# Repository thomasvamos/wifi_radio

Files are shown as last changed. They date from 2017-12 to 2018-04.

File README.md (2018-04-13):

# Raspberry-PI Wifi-Radio
My attempt to build a retro wifi radio from scratch using a raspberry pi, arduinos encased in an old radio Loewe Opta Bella-Luxus 2711W. I started the project in 2014 and worked on it sporadically, when I had time and motivation.

# Getting started
## Prerequisites
You will need the following hardware if you want to rebuilt this radio as it is:
* 1 x raspberry pi (I used a Raspberry Pi Model B Rev 2.0)
* 2 x Arduino Pro Mini
* 1 x hd44780 4x20 LCD Display
* 2 x push-button rotary encoders
* 1 x 5V/3.3V Logic Level Converter
* 1 x PAM8403 3W Amplifier
* 2 x 3 Ohm Speakers
* 1 x wifi dongle
* 1 x 25 Watt power source
* 1 x USB Soundcard (optional)
* Cables and passive components

The hardware used in the current setup is not optimal, as the project started with some components I had laying around and grew over time. Feel free to change it to your taste.

The following schematic shows, how the hardware is tied together:
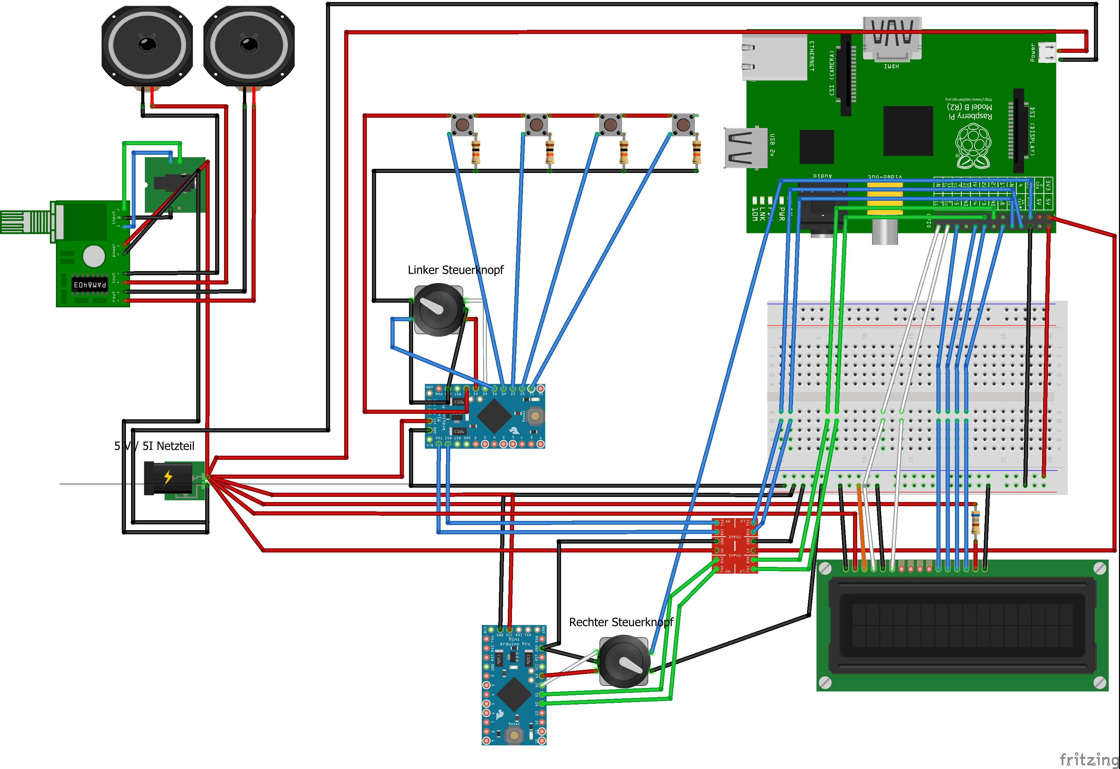
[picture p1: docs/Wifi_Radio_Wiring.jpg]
Radio schematic


## Installation
The project is quite hardware dependent, so you will have to do some configuration up front. [This](https://www.raspberrypi.org/documentation/configuration/wireless/wireless-cli.md) guide will help you, if you don't know how to connect your RPI to a wifi and [this](https://www.raspberrypi.org/documentation/remote-access/ssh/guide) one to set up SSH access. As the GPIO pins of the raspberry pi are limited, one of the arduinos is communicating to the RPI over serial communication. By default, the RPIs serial port is configured for console input/output. [This](http://www.instructables.com/id/Read-and-write-from-serial-port-with-Raspberry-Pi/) guide shows you how to disable it for Raspbian and [this](http://www.hobbytronics.co.uk/raspberry-pi-serial-port) one if you intend to run the radio on debian.

One of my goals for the radio was to completely cut off the power supply if the RPI shuts down. I did not find any suitable solutions so I designed a circuit for this purpose. You can find the schematics in the /docs folder. The RPI can be configured to set a pin from high to low if it shuts down. The curcuit probes this pin and cuts of power, if it is set to low. The following line has to be added to `/boot/config.txt` to enable this functionality:

    dtoverlay=gpio-poweroff,gpiopin=17,active_low=1

It is not required, but if you intend to use a USB soundcard you can check out this [guide](https://computers.tutsplus.com/articles/using-a-usb-audio-device-with-a-raspberry-pi--mac-55876) guide by Jordan Merrick.

With all the hardware setup being done, we finally can install the software via pip:

    $> pip install wifi_radio

### Running the tests
To run the tests simply navigate to the root of the project and run:

    $> python -m unittest discover

# Acknowledgments
The RPI, python and other communities were valueable sources of knowledge and inspiration. The following were particularly useful. Thanks guys!
* Inspiration
  * [Sheldon Hartling](http://usualpanic.com/2013/05/raspberry-pi-internet-radio/)
* LCD
  * [Matt Hawkins - LCD Control](http://www.raspberrypi-spy.co.uk/2012/08/20x4-lcd-module-control-using-python/)
  * [Alan Aufderheide - LCD Menu](https://github.com/aufder/RaspberryPiLcdMenu/blob/master/lcdmenu.py)
* Deployment and configuration
  * [Matt Hawkins - Start radio at boot](https://www.raspberrypi-spy.co.uk/2015/10/how-to-autorun-a-python-script-on-boot-using-systemd/)
  * [Jordan Merrick - USB Soundcard Configuration](https://computers.tutsplus.com/articles/using-a-usb-audio-device-with-a-raspberry-pi--mac-55876)
  * [setup.py with systemd registration](https://github.com/python-diamond/Diamond/blob/master/setup.py)
  * [Timezone settings for debian](https://d0m.me/2008/07/21/debian-linux-zeitzone-und-uhr-umstellen-deutschlandgermany/)

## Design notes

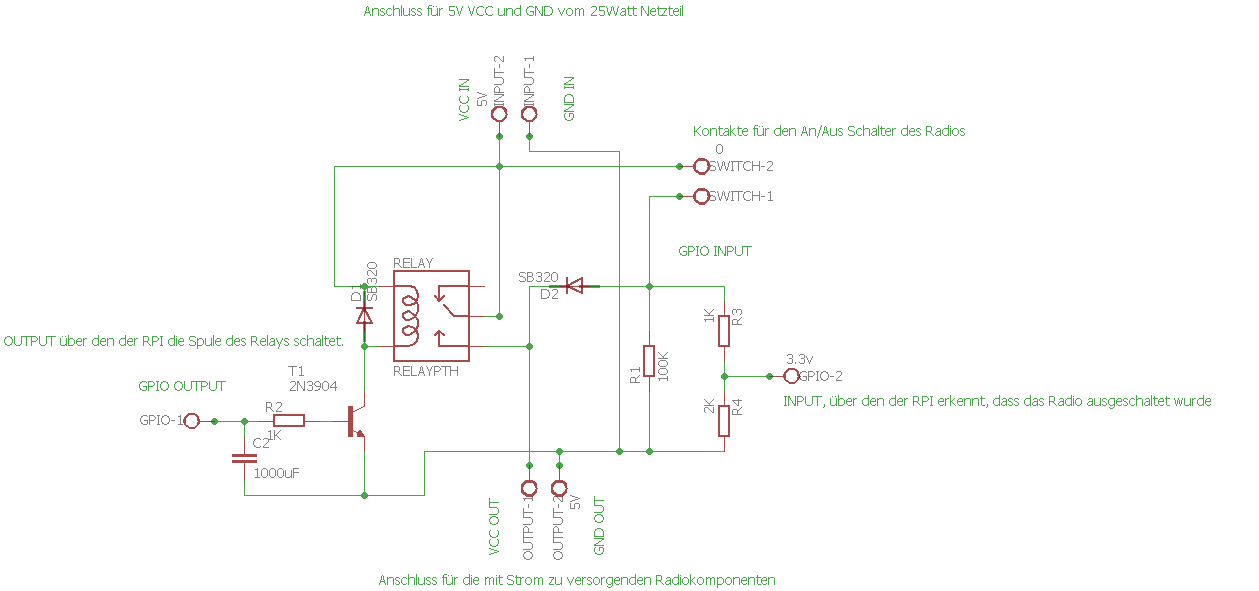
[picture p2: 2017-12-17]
docs/RPI_Shutdown.png

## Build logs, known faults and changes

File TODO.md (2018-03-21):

# TODOs

* Package python module
  * [Packaging](https://jeffknupp.com/blog/2013/08/16/open-sourcing-a-python-project-the-right-way/)
* Block Input until stations are loaded
* Optimize volume control (too slow)
* Read configs from file
* Disable DHCP and setup static IP Adress
* Play last played station
* Select station from menu
* Structure project according to best practices
* Install and Uninstall scripts for debian
* Optimize Startup Speed
* Unpause prints "Pause"

# Solved TODOs
* Playback using mpd
* Output over USB Soundcard
* Startup Radio on Boot (systemd service)

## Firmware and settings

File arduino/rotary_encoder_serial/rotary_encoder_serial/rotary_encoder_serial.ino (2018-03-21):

#include <RotaryEncoder.h>

// Setup a RoraryEncoder for pins A2 and A3:
RotaryEncoder encoder(A2, A3);

const int rotaryRightMsg = 66;
const int rotaryLeftMsg = 99;

// button for rotary encoder
const int buttonPin1 = A1;
int buttonState1;             // the current reading from the input pin
int lastButtonState1 = LOW;   // the previous reading from the input pin
unsigned long lastDebounceTime1 = 0;  // the last time the output pin was toggled

// button "TA" on the radio
const int buttonPin2 = A0;
int buttonState2;             // the current reading from the input pin
int lastButtonState2 = LOW;   // the previous reading from the input pin
unsigned long lastDebounceTime2 = 0;  // the last time the output pin was toggled

// button "LW" on the radio
const int buttonPin3 = 13;
int buttonState3;             // the current reading from the input pin
int lastButtonState3 = LOW;   // the previous reading from the input pin
unsigned long lastDebounceTime3 = 0;  // the last time the output pin was toggled

// button "MW" on the radio
const int buttonPin4 = 12;
int buttonState4;             // the current reading from the input pin
int lastButtonState4 = LOW;   // the previous reading from the input pin
unsigned long lastDebounceTime4 = 0;  // the last time the output pin was toggled

// button "UW" on the radio
const int buttonPin5 = 11;
int buttonState5;             // the current reading from the input pin
int lastButtonState5 = LOW;   // the previous reading from the input pin
unsigned long lastDebounceTime5 = 0;  // the last time the output pin was toggled

// button "BASS" on the radio
const int buttonPin6 = 10;
int buttonState6;             // the current reading from the input pin
int lastButtonState6 = LOW;   // the previous reading from the input pin
unsigned long lastDebounceTime6 = 0;  // the last time the output pin was toggled

// button "BASS" on the radio
const int buttonPin7 = 9;
int buttonState7;             // the current reading from the input pin
int lastButtonState7 = LOW;   // the previous reading from the input pin
unsigned long lastDebounceTime7 = 0;  // the last time the output pin was toggled

// button "BASS" on the radio
const int buttonPin8 = 8;
int buttonState8;             // the current reading from the input pin
int lastButtonState8 = LOW;   // the previous reading from the input pin
unsigned long lastDebounceTime8 = 0;  // the last time the output pin was toggled

// button "BASS" on the radio
const int buttonPin9 = 7;
int buttonState9;             // the current reading from the input pin
int lastButtonState9 = LOW;   // the previous reading from the input pin
unsigned long lastDebounceTime9 = 0;  // the last time the output pin was toggled

unsigned long debounceDelay = 50;    // the debounce time; increase if the output flickers

void setup()
{
  Serial.begin(9600);

  // You may have to modify the next 2 lines if using other pins than A2 and A3
  PCICR |= (1 << PCIE1);    // This enables Pin Change Interrupt 1 that covers the Analog input pins or Port C.
  PCMSK1 |= (1 << PCINT10) | (1 << PCINT11);  // This enables the interrupt for pin 2 and 3 of Port C.

  // button pins
  pinMode(buttonPin1, INPUT);
  digitalWrite(buttonPin1, HIGH);
  pinMode(buttonPin2, INPUT);
  digitalWrite(buttonPin2, HIGH);
//  pinMode(buttonPin3, INPUT);
//  digitalWrite(buttonPin3, HIGH);
//  pinMode(buttonPin4, INPUT);
//  digitalWrite(buttonPin4, HIGH);
//  pinMode(buttonPin5, INPUT);
//  digitalWrite(buttonPin5, HIGH);
//  pinMode(buttonPin6, INPUT);
//  digitalWrite(buttonPin6, HIGH);
//  pinMode(buttonPin7, INPUT);
//  digitalWrite(buttonPin7, HIGH);
//  pinMode(buttonPin8, INPUT);
//  digitalWrite(buttonPin8, HIGH);
//  pinMode(buttonPin9, INPUT);
//  digitalWrite(buttonPin9, HIGH);
}

// The Interrupt Service Routine for Pin Change Interrupt 1
// This routine will only be called on any signal change on A2 and A3: exactly where we need to check.
ISR(PCINT1_vect) {
  encoder.tick(); // just call tick() to check the state.
}


// Read the current position of the encoder and print out when changed.
void loop()
{
  processRotaryEncoderState();
  processButtonState(&buttonPin1, &buttonState1, &lastButtonState1, &lastDebounceTime1);
  processButtonState(&buttonPin2, &buttonState2, &lastButtonState2, &lastDebounceTime2);
//  processButtonState(&buttonPin3, &buttonState3, &lastButtonState3, &lastDebounceTime3);
//  processButtonState(&buttonPin4, &buttonState4, &lastButtonState4, &lastDebounceTime4);
//  
//  processButtonState(&buttonPin5, &buttonState5, &lastButtonState5, &lastDebounceTime5);
//  processButtonState(&buttonPin6, &buttonState6, &lastButtonState6, &lastDebounceTime6);
//  processButtonState(&buttonPin7, &buttonState7, &lastButtonState7, &lastDebounceTime7);
//  processButtonState(&buttonPin8, &buttonState8, &lastButtonState8, &lastDebounceTime8);
//  processButtonState(&buttonPin9, &buttonState9, &lastButtonState9, &lastDebounceTime9);
} 

void processRotaryEncoderState() {
  static int pos = 0;
  int newPos = encoder.getPosition();
  if (pos != newPos) {
    if(newPos > pos) {
      // "Right turn"
      Serial.println(rotaryRightMsg, DEC);
    } else {
      // "Left turn"
      Serial.println(rotaryLeftMsg, DEC);
    }
    pos = newPos;
  }
}

void processButtonState(const int *buttonPin, int *buttonState, int *lastButtonState, unsigned long *lastDebounceTime) {
  // read the state of the switch into a local variable:
  int reading = digitalRead(*buttonPin);

  // check to see if you just pressed the button
  // (i.e. the input went from LOW to HIGH),  and you've waited
  // long enough since the last press to ignore any noise:

  // If the switch changed, due to noise or pressing:
  if (reading != *lastButtonState) {
    // reset the debouncing timer
    *lastDebounceTime = millis();
  }

  if ((millis() - *lastDebounceTime) > debounceDelay) {
    // whatever the reading is at, it's been there for longer
    // than the debounce delay, so take it as the actual current state:

    // if the button state has changed:
    if (reading != *buttonState) {
      *buttonState = reading;

      // only toggle the LED if the new button state is HIGH
      if (*buttonState == HIGH) {
        Serial.println(*buttonPin, DEC);
      }
    }
  }

  // save the reading.  Next time through the loop,
  // it'll be the lastButtonState:
  *lastButtonState = reading;

}

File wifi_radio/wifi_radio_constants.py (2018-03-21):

'''
Constants for GPIO pins and message indicators
'''

class WifiRadioConstants(object):

  # GPIO input pins for rotary encoders
  VOLUME_ROTARY_LEFT_TURN_PIN = 22 #GPIO_3
  VOLUME_ROTARY_RIGHT_TURN_PIN = 27 #GPIO_2
  VOLUME_ROTARY_BUTTON_PIN = 3 #SCL

  # Input Pin to tell the radio to init shutdown
  SHUTDOWN_INPUT = 10 #MOSI

  # GPIO output pins for the LCD mapping
  LCD_RS = 7
  LCD_E  = 8
  LCD_D4 = 25 
  LCD_D5 = 24
  LCD_D6 = 23
  LCD_D7 = 18
  # LED_ON = 15 # hard wired, always on

  # Rotary encoder messages for multihtread communication
  MENU_LEFT_TURN_MSG = 0
  MENU_RIGHT_TURN_MSG = 1
  MENU_PRESSED_MSG = 2

  VOLUME_LEFT_TURN_MSG = 3
  VOLUME_RIGHT_TURN_MSG = 4
  VOLUME_PRESSED_MSG = 5
  
  TICK = 6
  SHUTDOWN_MSG = 7
  

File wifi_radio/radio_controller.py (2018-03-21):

'''
Delegates inputs to active mode
'''

from mode_selector import ModeSelector

class RadioController(object):

  def __init__(self):
    self.modeSelector = ModeSelector()

  def tick(self):
    self.modeSelector.mode.tick()

  def handleMenuLeftTurn(self):
    self.modeSelector.mode.handleMenuLeftTurn()

  def handleMenuRightTurn(self):
    self.modeSelector.mode.handleMenuRightTurn()

  def handleMenuPress(self):
    self.modeSelector.mode.handleMenuPress()

  def handleVolumeLeftTurn(self):
    self.modeSelector.mode.handleVolumeLeftTurn()

  def handleVolumeRightTurn(self):
    self.modeSelector.mode.handleVolumeRightTurn()

  def handleVolumePress(self):
    self.modeSelector.mode.handleVolumePress()

  def handleShutdown(self):
    self.modeSelector.mode.handleShutdown()




  

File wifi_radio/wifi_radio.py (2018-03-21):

#!/usr/bin/env python
'''
Raspberry Pi Wifi Radio

Created: 14.09.2014
'''

import RPi.GPIO as GPIO
from wifi_radio_constants import WifiRadioConstants as WRC
from radio_controller import RadioController
import time
from time import sleep
import signal
import serial
import logging
import configuration as cfg

__author__ = "Thomas Vamos"
__license__ = "MIT"
__version__ = "0.0.1"
__maintainer__ = "Thomas Vamos"
__email__ = "mail@thomasvamos.de"

class WifiRadio(object):

    def __init__(self):

        self.initLogger()

        # initialize serial port
        ser = serial.Serial('/dev/ttyAMA0', 9600, timeout=1)

        self.initGpio()

        self.radioController = RadioController()

        self.tickInterval = 10
        self.tickExecCounter = self.tickInterval
        
        # pause thread
        try:
            while 1:
                response = ser.readline().strip()
                if response == "66":
                    self.isr_menu_right(0)
                elif response == "99":
                    self.isr_menu_left(0)
                elif response == "15":
                    self.isr_menu_press(0)

                self.radioController.tick()

        except KeyboardInterrupt:
            GPIO.cleanup()
            ser.close()

    def initLogger(self):
        logging.basicConfig(filename=cfg.log_file,level=logging.DEBUG)

    def initGpio(self):
        GPIO.setwarnings(False)
        GPIO.setmode(GPIO.BCM)

        # set up GPIOs as inputs.

        # set up press buttons
        GPIO.setup(WRC.VOLUME_ROTARY_BUTTON_PIN, GPIO.IN, pull_up_down=GPIO.PUD_DOWN)
        GPIO.add_event_detect(WRC.VOLUME_ROTARY_BUTTON_PIN, GPIO.RISING, callback=self.isr_volume_press)  

        # set up volume rotary encoder
        GPIO.setup(WRC.VOLUME_ROTARY_LEFT_TURN_PIN, GPIO.IN, pull_up_down=GPIO.PUD_DOWN)
        GPIO.setup(WRC.VOLUME_ROTARY_RIGHT_TURN_PIN, GPIO.IN, pull_up_down=GPIO.PUD_DOWN)
        GPIO.add_event_detect(WRC.VOLUME_ROTARY_LEFT_TURN_PIN, GPIO.RISING, callback=self.isr_volume_left)  
        GPIO.add_event_detect(WRC.VOLUME_ROTARY_RIGHT_TURN_PIN, GPIO.RISING, callback=self.isr_volume_right)  

        GPIO.setup(WRC.SHUTDOWN_INPUT, GPIO.IN, pull_up_down=GPIO.PUD_UP)
        GPIO.add_event_detect(WRC.SHUTDOWN_INPUT, GPIO.FALLING, callback=self.shutdown)

    def isr_volume_left(self, channel):
        # print "Volume turn left"
        self.radioController.handleVolumeLeftTurn()

    def isr_volume_right(self, channel):
        # print "Volume turn right"
        self.radioController.handleVolumeRightTurn()

    def isr_volume_press(self, channel):
        # print "Volume button pressed"
        self.radioController.handleVolumePress()

    def isr_menu_left(self, channel):
        # print "Menu turn left"
        self.radioController.handleMenuLeftTurn()

    def isr_menu_right(self, channel):
        # print "Menu turn right"
        self.radioController.handleMenuRightTurn()

    def isr_menu_press(self, channel):
        self.radioController.handleMenuPress()

    def shutdown(self, channel):
        # print "Shutdown..."
        self.radioController.handleShutdown()

if __name__ == '__main__':
    WifiRadio()

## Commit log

2014-09-14 Print station name.
2014-10-15 Add lcd print util
2014-10-15 Add rotary encoder utility class
2014-10-23 Control lcd with rotary encoder.
2014-11-09 Finish implementation of rotary encoders with lcd message queue.
2016-06-19 Umbau mit Arduino rotary encoder implementierung.
    [Wifi_Radio_Wiring.fzz]
2016-07-03 Integrated LCD and MPC with the rotary encoders.
2016-10-12 Adding consumption of serial port data.
    [Wifi_Radio_Wiring.fzz]
2016-12-06 Updated volume control to python-mpd2 library.
    [Wifi_Radio_Wiring.fzz]
2017-12-17 Added logic for gracious shutdown.
    [Ausschaltlogik.fzz, Wifi_Radio_Wiring.fzz]
2017-12-27 Switch to rplcd library
2018-01-01 Convert operation to single thread
2018-01-02 Create Thread for LCD operations and make MPDClient threadsafe
2018-01-07 Display title for current song
2018-01-07 Set correct timezone in install script
    [lcd_print_util.py]
2018-01-08 Fix display output on shutdown
    [lcd_print_util.py]
2018-03-21 Restructure code into module structure.
    [Ausschaltlogik.fzz, Wifi_Radio_Wiring.fzz]
2018-04-13 Update docs
    [RPI_Shutdown.fzz]
